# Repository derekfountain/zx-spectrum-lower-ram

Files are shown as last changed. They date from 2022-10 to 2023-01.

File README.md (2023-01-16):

# zx-spectrum-lower-ram

## A lower RAM module for the ZX Spectrum

This is a hardware module which implements the lower 16K RAM bank for a
16K or 48K ZX Spectrum microcomputer.

The memory bank is normally implemented with 8 4116 DRAM ICs. These
ICs are no longer in production, and although not yet hard to get hold
of, the ones which are available are 50 years old and have inevitable
frailties. This project implements the required 16K of memory using a
modern SRAM IC.

The project is a plug in replacement, replacing this:

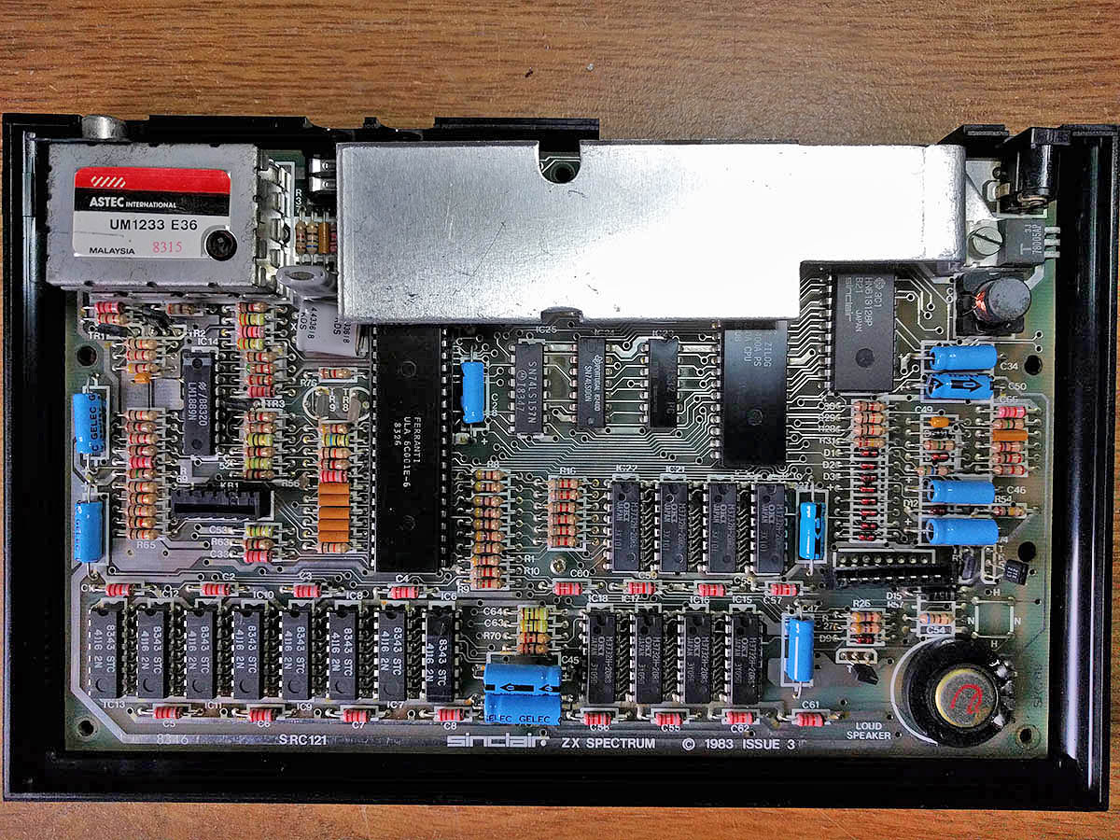
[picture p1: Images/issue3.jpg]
Spectrum circuit board


with this:

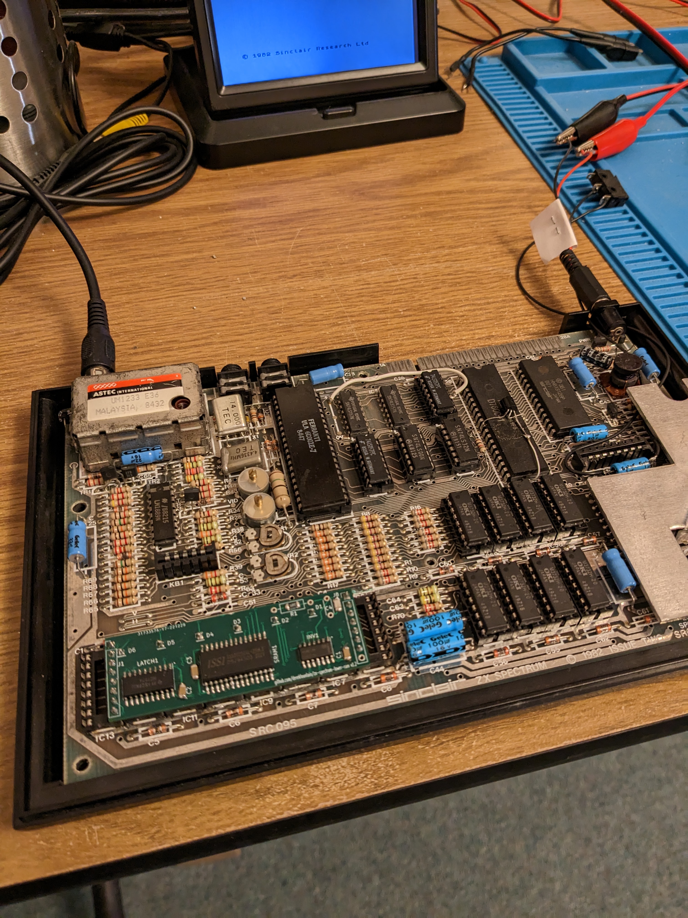
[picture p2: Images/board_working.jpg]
Board working


(And yes, that's a different Spectrum in those 2 photos. :))

At the time of implemention, there was no open source design for this type
of memory board. Hence I created one.

## Design

The Spectrum uses a multiplexed address system common of low cost micros of
the 70s and 80s. It addresses the memory ICs twice, first with a 7-bit row
address ("RAS") value, then about 50ns later with a 7-bit column address
("CAS") value. That's how the 4116 ICs work. The advange to those ICs is
that it only requires 7 address lines, rather than the 14 which would
otherwise be required to address 16K.

None of that is required any more and modern RAM ICs have all the address
lines they require. The modern design is therefore to use a latch triggered on the row
address strobe (RAS) to store the first 7 bits of the address, then pass those and
the other 7 bits of the address into the address lines of a modern
SRAM IC when the CAS signal arrives. It turns out that the SRAM will remove
its data from its output bus slightly too soon for the Spectrum's ULA, so
a small timer circuit is needed to slow the CAS signal down a few nanoseconds.

16K SRAMs are difficult to get hold of these days, and tend to be rather
expensive. This project uses a 32K SRAM and ignores the top 16K of it.

I've only tested the design with the Ferranti 6C001E-6 and Ferranti 6C001E-7
ULAs. It's possible some timing tweaks might be required for other ULAs.

## KiCAD Project

The project is implemented in KiCAD v6. It's in the slrm/ directory. ((S)pectrum
(L)ower ( R)AM (M)odule.)

There are a couple of snapshots of early implementations of the project. One of
these is a "breakout" version of the board which might be useful to
investigate signals using a 'scope.

## Fabrication

The Gerber files which can be sent directly for fabrication are to be found
in slrm/fab1.2/fab1.2.zip. You can just upload that ZIP to JLCPCB (which is
what I did). Default values for JLCPCB's fabrication process
will do fine except for the board thickness. Set that to 1.00mm. It's very
tight under the Spectrum's keyboard.

## Bill of Materials

1x [IS62C256AL-25ULI-TR 32K SRAM](https://www.mouser.co.uk/ProductDetail/870-62C256AL-25ULIT)
32K SRAM IC
<br>
1x [74HCT574](https://www.mouser.co.uk/ProductDetail/595-SN74HCT574NSR)
8 bit flip flop latch
<br>
1x [74HCT04](https://www.mouser.co.uk/ProductDetail/863-MC74HCT04ADG)
6 circuit inverter
<br>
3x [3216 SMD 0.1uF capacitor](https://www.mouser.co.uk/ProductDetail/581-12065C104KAT4A)
Capacitor
<br>
1x [3216 68R SMD resistor](https://www.mouser.co.uk/ProductDetail/603-RT1206FRE0768RL)
Resistor
<br>
1x [3216 SMD 100pF capacitor](https://www.mouser.co.uk/ProductDetail/581-12065A101J)
Capacitor
<br>
22x Arduino type 2.54mm Pin header connectors

## Assembly

Any 62256-standard SRAM IC should work. The ISSI one I chose was the cheapest
at Mouser. The [Alliance Memory](https://www.mouser.co.uk/ProductDetail/913-CY62256NLL55SNXI)
one should be fine as well. Solder the SRAM first, then do the latch and the inverter, then
their decoupling capacitors. Then do the resistor and capacitor for the timer circuit.
Through the hole footprints are also available for these last two components, but they make
the keyboard refit extremely tight. They work, but use SMD if you can.

## Pin Length

The pins need to protrude below the board and fit into the sockets (or PCB if you're
soldering directly), but they mustn't be any longer than absolutely necessary
otherwise the board will stand too proud on the Spectrum PCB and the keyboard won't
fit back on.

The correct length for all the boards I've made up is 4.2mm protruding. This is very
difficult to get accurate and consistent with cutters, so I made a 3D printed jig.
That's in the slrm/3D directory, both as an SCAD source file and a STL file. If you
take this route, place the jig over the pins:

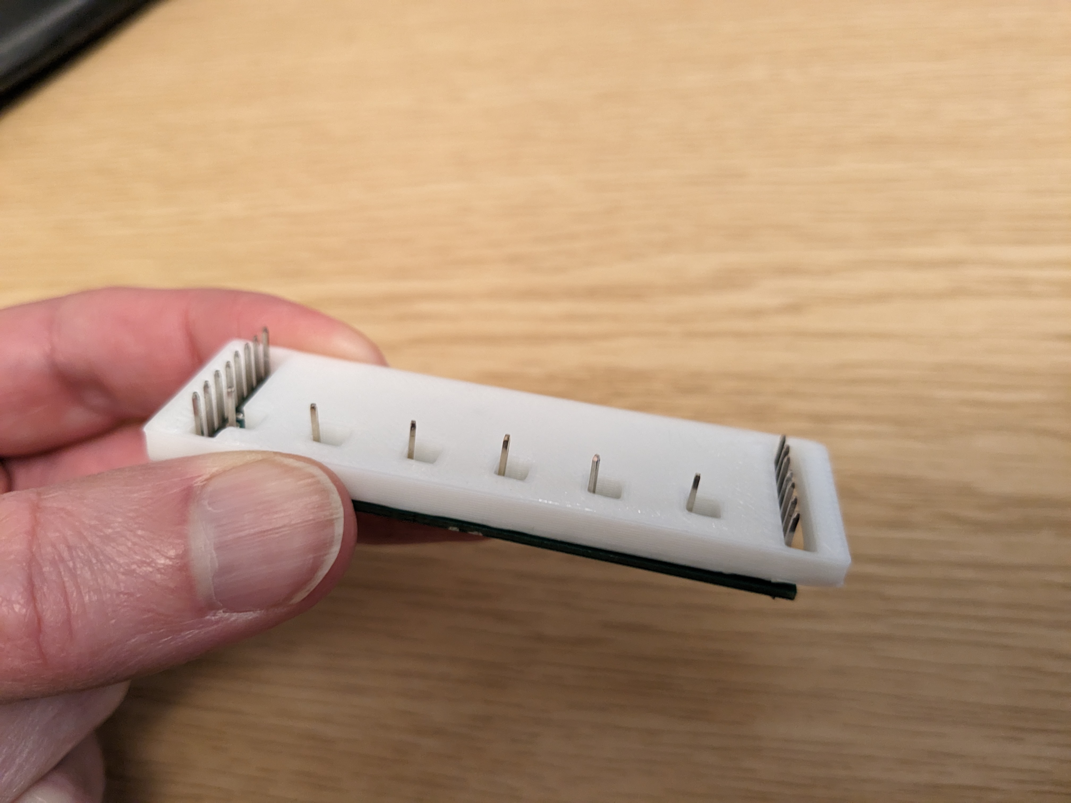
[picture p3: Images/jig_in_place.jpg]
Jig


then use a rotary tool or similar to grind the pins to the correct length:

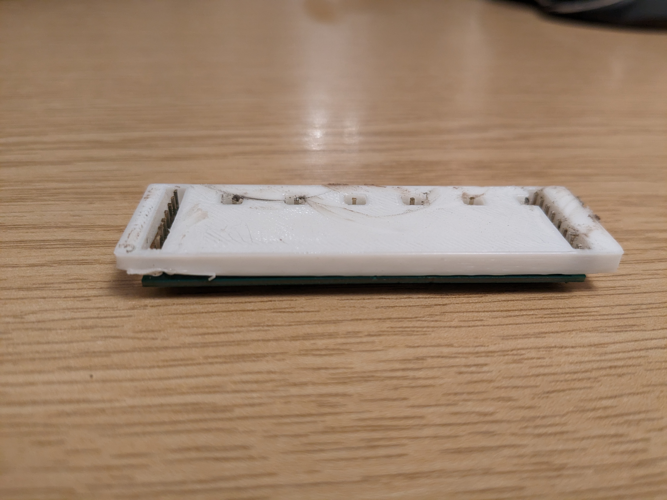
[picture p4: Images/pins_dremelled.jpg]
Pins Dremelled

Pins Correct

## Fitting

Once assembled, and with the pins the right length, the board then just presses into
the sockets on the Spectrum PCB:

Board working

Note the fitting: the board doesn't span the entire width of the 8 4116 ICs. The outer
most sides of the two end sockets aren't used.

## More Information

There's a bit more information on how it works on [my website](https://www.derekfountain.org/my_zx_lower_ram.php),
and a few more photos and discussion on it over at
[Spectrum Computing](https://spectrumcomputing.co.uk/forums/viewtopic.php?t=8782).

[Derek Fountain](https://www.derekfountain.org/), January 2023

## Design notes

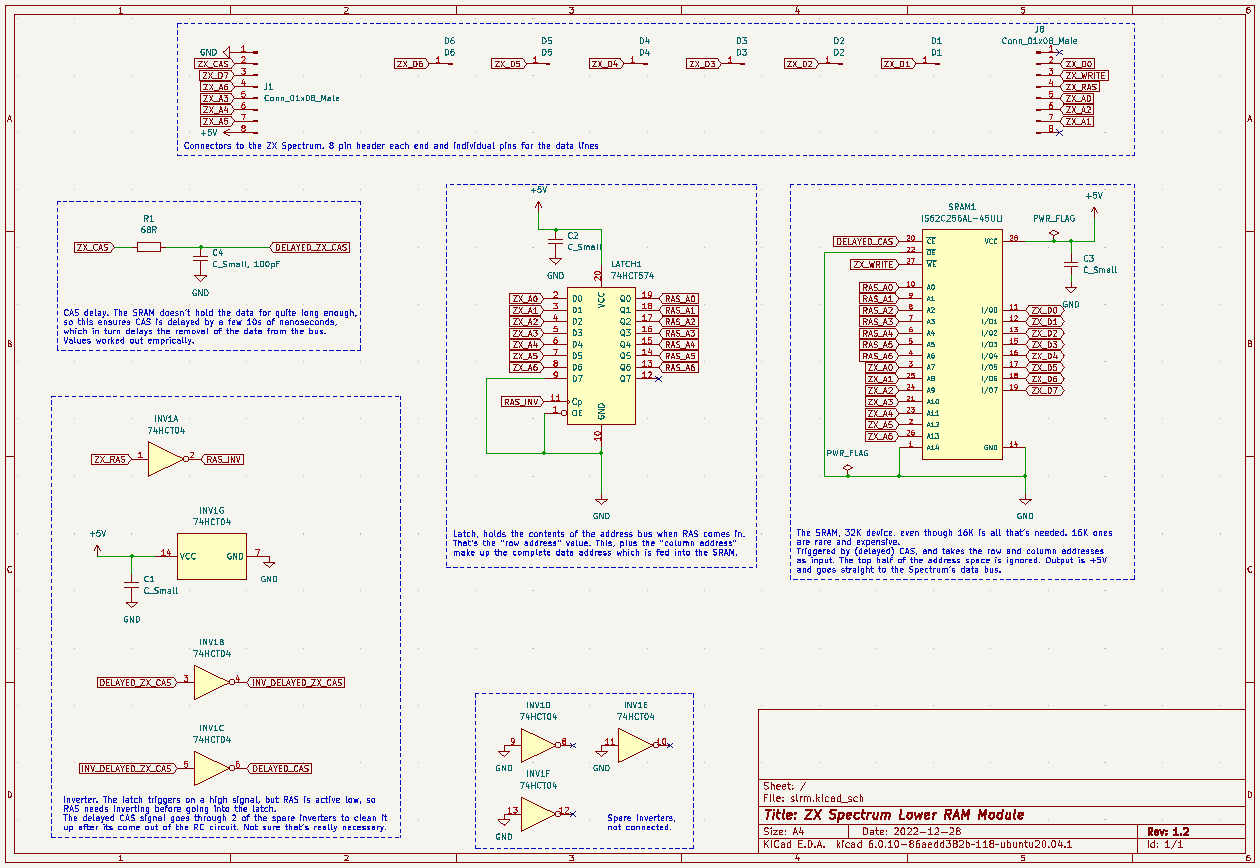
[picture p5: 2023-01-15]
Images/slrm-schematic.png

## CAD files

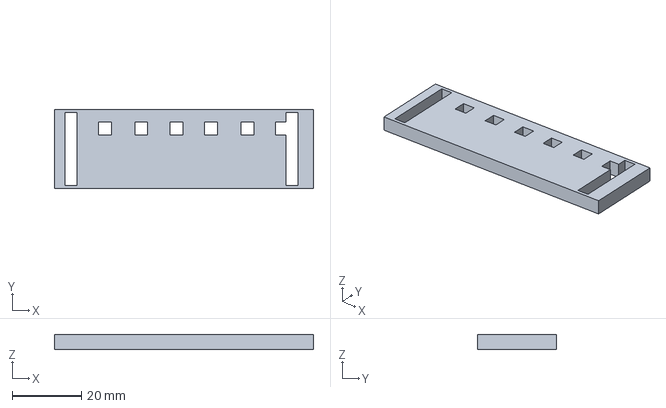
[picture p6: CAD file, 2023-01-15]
slrm/3D/pin_jig.3mf
75.0 x 23.0 x 4.20 mm

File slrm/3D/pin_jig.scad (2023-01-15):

linear_extrude( 4.2 )   // Measured the depth of a working board's pins
{
  difference()
  {
    green_board_height=23.0;
    
    square( [75, green_board_height] );
    
    _8_pins_height = 21.0;
    translate( [3, 1, 0] )           // 3 in, 1 up
      square( [3.5, _8_pins_height] ); //3mm is width of a row of pins.

    hole_diameter = 3.75;
    translate( [12.75, 15.5, 0] )  //Leftmost pin hole
      square( [hole_diameter, hole_diameter] );
  
    translate( [23.25, 15.5, 0] )  
      square( [hole_diameter, hole_diameter] );

    translate( [33.5, 15.5, 0] ) 
      square( [hole_diameter, hole_diameter] );

    translate( [43.5, 15.5, 0] )  
      square( [hole_diameter, hole_diameter] );

    translate( [54.0, 15.5, 0] )  
      square( [hole_diameter, hole_diameter] );

    translate( [64.0, 15.5, 0] )  
      square( [hole_diameter, hole_diameter] );

    translate( [67.0, 1, 0] )        
      square( [3.5, _8_pins_height] ); 

  }
}

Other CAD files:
slrm/3D/pin_jig.stl

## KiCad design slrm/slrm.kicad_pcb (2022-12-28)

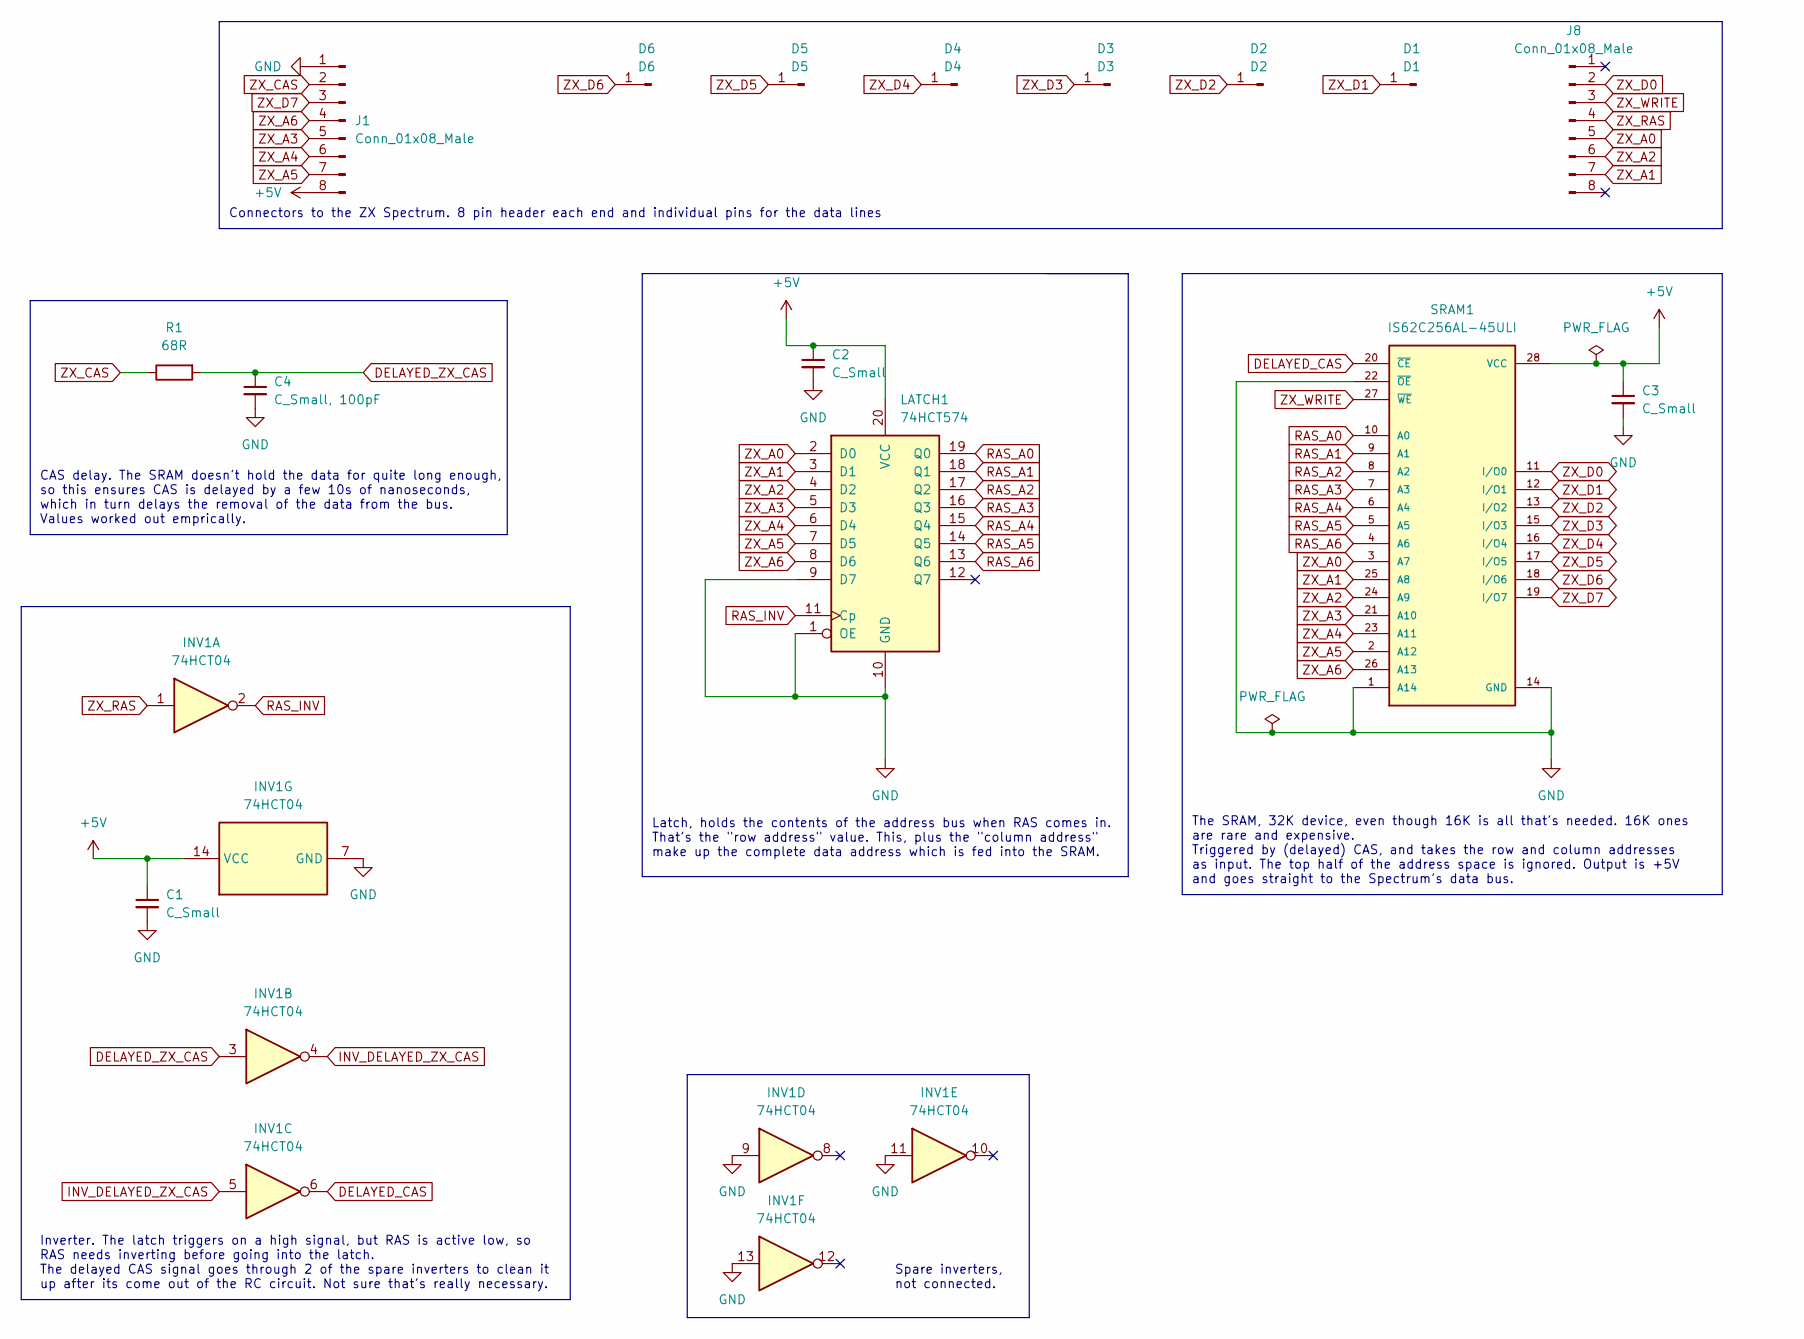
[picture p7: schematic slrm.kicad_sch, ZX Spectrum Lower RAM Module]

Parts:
C1, C2, C3: C_Small; C_1206_3216Metric
C4: C_Small, 100pF; C_Disc_D4.3mm_W1.9mm_P5.00mm
D1: D1; PinHeader_1x01_P2.00mm_Vertical
D2: D2; PinHeader_1x01_P2.00mm_Vertical
D3: D3; PinHeader_1x01_P2.00mm_Vertical
D4: D4; PinHeader_1x01_P2.00mm_Vertical
D5: D5; PinHeader_1x01_P2.00mm_Vertical
D6: D6; PinHeader_1x01_P2.00mm_Vertical
INV1: 74HCT04; SOIC-14_3.9x8.7mm_P1.27mm
J1, J8: Conn_01x08_Male; PinHeader_1x08_P2.54mm_Vertical
LATCH1: 74HCT574; SO-20_5.3x12.6mm_P1.27mm
R1: 68R; R_Axial_DIN0207_L6.3mm_D2.5mm_P10.16mm_Horizontal
SRAM1: IS62C256AL-45ULI; SOIC127P1210X305-28N

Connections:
+5V: C1.1, C2.1, C3.1, INV1.14 (VCC), J1.8, LATCH1.20 (VCC), SRAM1.28 (VCC)
DELAYED_CAS: INV1.6, SRAM1.20 (~CE)
DELAYED_ZX_CAS: C4.1, INV1.3, R1.2; also elsewhere on the board
GND: C1.2, C2.2, C3.2, C4.2, INV1.7 (GND), INV1.9, INV1.11, INV1.13, J1.1, LATCH1.1 (OE), LATCH1.9 (D7), LATCH1.10 (GND), SRAM1.1 (A14), SRAM1.14 (GND), SRAM1.22 (~OE); also elsewhere on the board
INV_DELAYED_ZX_CAS: INV1.4, INV1.5
RAS_A0: LATCH1.19 (Q0), SRAM1.10 (A0)
RAS_A1: LATCH1.18 (Q1), SRAM1.9 (A1)
RAS_A2: LATCH1.17 (Q2), SRAM1.8 (A2)
RAS_A3: LATCH1.16 (Q3), SRAM1.7 (A3)
RAS_A4: LATCH1.15 (Q4), SRAM1.6 (A4)
RAS_A5: LATCH1.14 (Q5), SRAM1.5 (A5)
RAS_A6: LATCH1.13 (Q6), SRAM1.4 (A6)
RAS_INV: INV1.2, LATCH1.11 (Cp)
ZX_A0: J8.5, LATCH1.2 (D0), SRAM1.3 (A7)
ZX_A1: J8.7, LATCH1.3 (D1), SRAM1.25 (A8)
ZX_A2: J8.6, LATCH1.4 (D2), SRAM1.24 (A9)
ZX_A3: J1.5, LATCH1.5 (D3), SRAM1.21 (A10)
ZX_A4: J1.6, LATCH1.6 (D4), SRAM1.23 (A11)
ZX_A5: J1.7, LATCH1.7 (D5), SRAM1.2 (A12)
ZX_A6: J1.4, LATCH1.8 (D6), SRAM1.26 (A13)
ZX_CAS: J1.2, R1.1
ZX_D0: J8.2, SRAM1.11 (I/O0)
ZX_D1: D1.1, SRAM1.12 (I/O1)
ZX_D2: D2.1, SRAM1.13 (I/O2)
ZX_D3: D3.1, SRAM1.15 (I/O3)
ZX_D4: D4.1, SRAM1.16 (I/O4)
ZX_D5: D5.1, SRAM1.17 (I/O5)
ZX_D6: D6.1, SRAM1.18 (I/O6)
ZX_D7: J1.3, SRAM1.19 (I/O7)
ZX_RAS: INV1.1, J8.4
ZX_WRITE: J8.3, SRAM1.27 (~WE)

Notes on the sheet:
Inverter. The latch triggers on a high signal, but RAS is active low, so RAS needs inverting before going into the latch. The delayed CAS signal goes through 2 of the spare inverters to clean it up after its come out of the RC circuit. Not sure that's really necessary.
Connectors to the ZX Spectrum. 8 pin header each end and individual pins for the data lines
Latch, holds the contents of the address bus when RAS comes in. That's the "row address" value. This, plus the "column address" make up the complete data address which is fed into the SRAM.
CAS delay. The SRAM doesn't hold the data for quite long enough, so this ensures CAS is delayed by a few 10s of nanoseconds, which in turn delays the removal of the data from the bus. Values worked out emprically.
Spare inverters, not connected.
The SRAM, 32K device, even though 16K is all that's needed. 16K ones are rare and expensive. Triggered by (delayed) CAS, and takes the row and column addresses as input. The top half of the address space is ignored. Output is +5V and goes straight to the Spectrum's data bus.

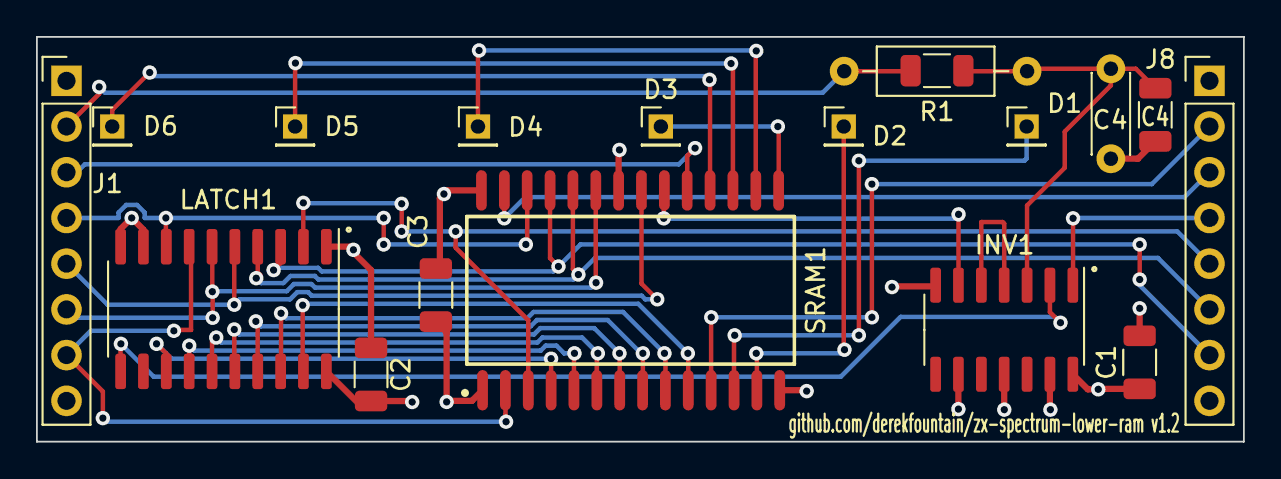
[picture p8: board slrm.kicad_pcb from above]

Board: 4 copper layers, 67.1 x 22.5 mm, 17 parts (0 on the bottom side), 31 nets.

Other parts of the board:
C4#2: C_Small; C_1206_3216Metric

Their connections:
DELAYED_ZX_CAS: C4#2.2; also elsewhere on the board
GND: C4#2.1; also elsewhere on the board

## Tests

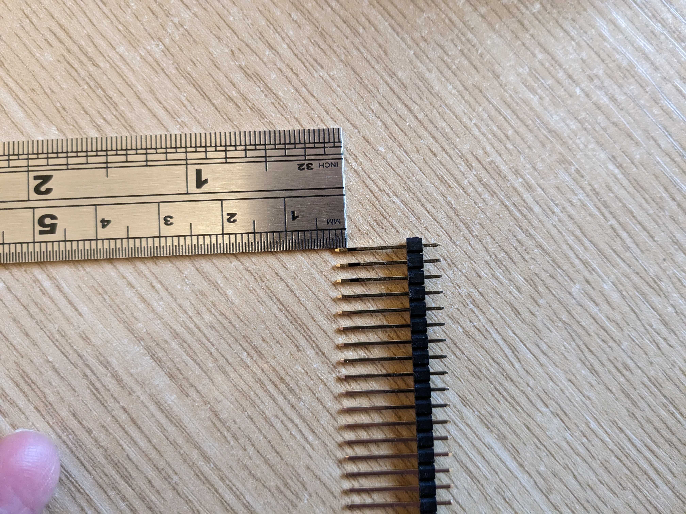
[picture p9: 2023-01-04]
Images/measure_depth.jpg

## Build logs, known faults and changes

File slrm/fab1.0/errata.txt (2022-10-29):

===
The 74HCT574 flip flop latch has footprint:
 Package_SO:SOIC-20W_7.5x12.8mm_P1.27mm
I'm working with the SN74HCT574NSR variant of the IC which is 5.6mm wide.
Hence that footprint needs to be:
 Package_SO:SO-20_5.3x12.6mm_P1.27mm
===
The board works, but "sparkles" appear on the Spectrum's screen. The Z80
is happy and all tests pass, but the ULA has some different, unspecified
requirements. Lots of experimentation suggests the SRAM's data needs to
be held on the data bus for a few nanoseconds after !CAS has gone high.
In theory the transaction is over by that point, but clearly something
isn't quite meeting requirements.

So I'm going to break the direct link between !CAS and the SRAM's !OE
and introduce a delay on the CAS line. It'll fire later, but also
delay the rising of CAS.
===
I changed the silkscreen labelling without changing the schematic, which
was a bit dumb. Need to fix that.
===
I need to get the signals from underneath the inverter where possible.
I had to take the IC off to cut some tracks.

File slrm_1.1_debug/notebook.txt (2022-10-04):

SRAM used is the IS65C256AL 32K x 8bit. CY62256 is an option, but a
bit more expensive.

Latch is 74HCT574. Identical to the 373, but the 574 has inputs on one side
and outputs on the other, which makes latching and passing through a
bus a lot easier to lay out.

ZX Write
========

RAS falls - we have min tRAH (20ns) to latch it
<275ns>
WRITE falls - it will stay down for min tWP (45ns)
<100ns>
CAS falls.
CAS address will stay available for tAR-tRCD(max) (95ns-50ns) is min 45ns.

Data will stay on the bus for min 45ns after CAS falls.

SRAM: Write cycle 1: CE, WR and addr can all go low at once, with
data input valid at that point. OE not used, can be either.

SRAM: Write cycle 2: CE remains low. OE goes high same time as address
appears. WR goes low at same time, or shortly after, with data valid at
that point.

SRAM: Write cycle 3: CE and OE remain low. Address and WR appear at the
same time, with data valid at that point.

ZX Read
=======

RAS falls - we have min tRAH (20ns) to latch it
<100ns>
CAS falls - it will be there for min tCAH (45ns)
We have a max of tCAC (100ns) to get the data onto the data bus
Can't work out how long it needs to be there.
<200ns>
CAS rises
<50ns>
CAS falls
<75ns>
RAS rises
<120ns>
RAS falls
CAS rises
<75ns>
CAS falls
<200ns>
CAS rises

Important point here is that from CAS going low, the SRAM needs
to have the data on the bus inside 100ns.

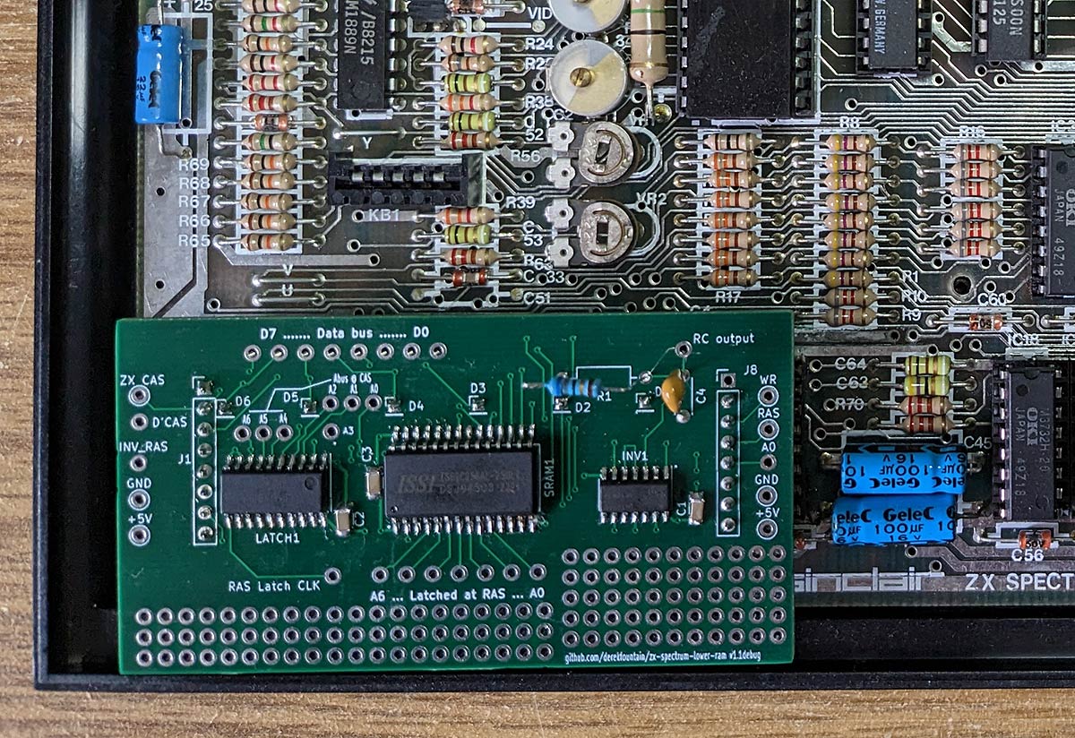
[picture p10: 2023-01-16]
Images/debug_board_sc.jpg

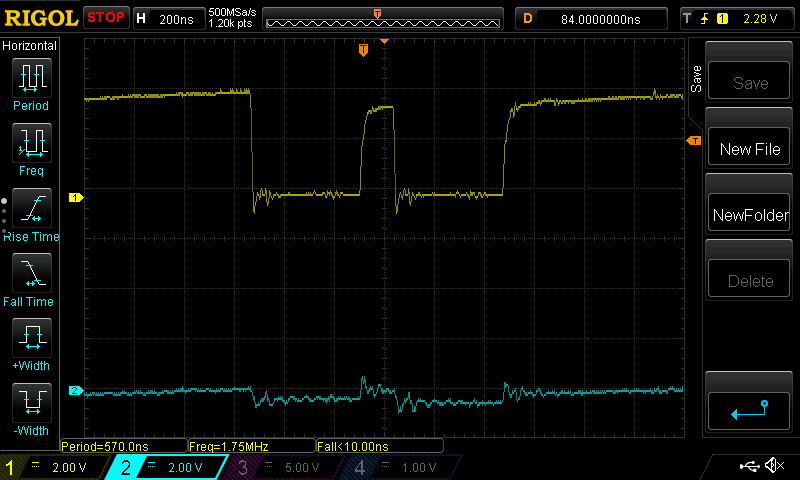
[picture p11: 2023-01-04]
__ATTIC/fixes/1M.png

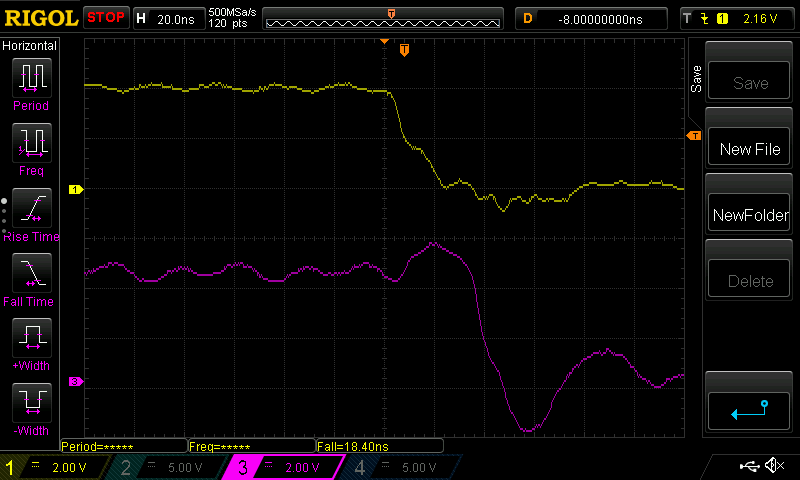
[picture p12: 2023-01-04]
__ATTIC/fixes/ard_falling_through_double_inv.png

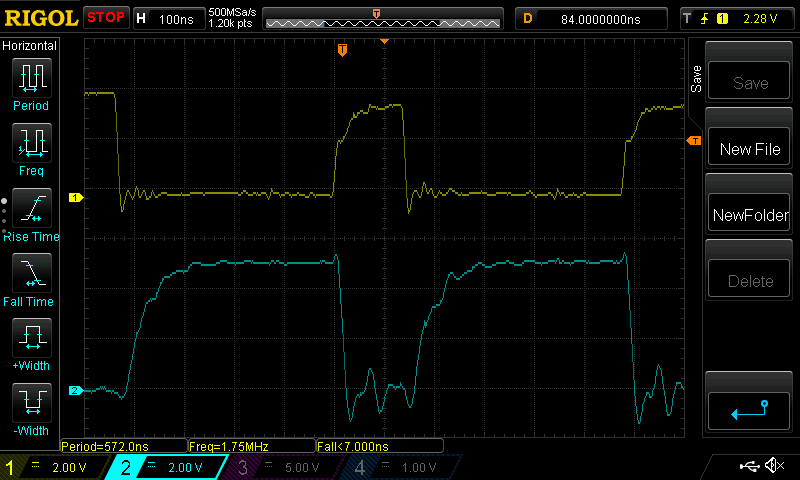
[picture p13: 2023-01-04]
__ATTIC/fixes/1K.png

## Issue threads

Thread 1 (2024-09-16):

Alternative pin headers

linker3000, 2024-09-16:
Thanks for developing and publishing this project.

Round pin headers might be a better bet than the square ones. The pins are shorter and more gentle on the socket contacts.

These headers are used frequently on vintage computer plug-ins, for example the SIDKick Pico.

Example:

https://www.aliexpress.com/item/4001122376295.html

derekfountain, 2024-09-16:
I should probably also add here that the grinding of the pins to the correct length is totally unnecessary, as pointed out in [this post](https://spectrumcomputing.co.uk/forums/viewtopic.php?p=109564#p109564) at Spectrum Computing.

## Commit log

2022-10-04 schematic worth keeping
    [slrm.kicad_pcb, slrm.kicad_sch, slrm.sch]
2022-10-04 more schematic work, ground inputs, find the footprint for the sram
    [slrm.kicad_sch]
2022-10-05 split out zx connections into individual connectors, power to the inverter
    [slrm.kicad_sch]
2022-10-05 use the right connectors
    [slrm.kicad_sch]
2022-10-06 layout complete
    [slrm.kicad_pcb, slrm.kicad_sch]
2022-10-06 final tweaks
    [slrm.kicad_pcb]
2022-10-06 v1.0, fab files sent off
    [slrm-B_Cu.gbl, slrm-B_Mask.gbs, slrm-B_Paste.gbp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]
2022-10-29 work towards fab2
    [slrm.kicad_pcb, slrm.kicad_sch]
2022-11-07 v1.1, added RC circuit to main design, added a breakout version (debug) and a duplication of a working circuit
    [slrm-B_Cu.gbl, slrm-B_Mask.gbs, slrm-B_Paste.gbp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]
2022-12-28 version 1.2 gerbers created
    [slrm-B_Cu.gbl, slrm-B_Mask.gbs, slrm-B_Paste.gbp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]
2023-01-15 v1.2 photos and 3d print of jig
    [pin_jig.3mf, pin_jig.scad, pin_jig.stl]
